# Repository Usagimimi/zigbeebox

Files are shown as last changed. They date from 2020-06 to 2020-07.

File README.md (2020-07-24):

# zigbeebox
Powerful zigbee coordinator with USB and debug port in metal enclosure.

### This project is still under development!!! 

## Description
[Zigbee in general.](https://en.wikipedia.org/wiki/Zigbee)

The coordinator is the central unit of the zigbee network, handling significant RF traffic in most cases. This project offers low-cost open-source hardware for this task, as a remix of many DIY coordinators out there. Takes a bit of time and basic soldering skills to assemble, but it can replace any manufacturers proprietary device when ready. Using the right firmware and server application, you can build a reliable, secure zigbee network without factory restrictions, involving almost any zigbee appliance. This opens the possibility to use IKEA Tradfri lights along with Xiaomi sensors, Philips Hue products, and many more in the same network, without the vendors gateway. The pcb utilizes a cheap chinese CC2538+CC2592 RF module with ARM Cortex-M3 based SoC and enough memory to serve a lot of connections with good performance.

The design heavily relies on open-source code, such as [Zigbee2MQTT](https://www.zigbee2mqtt.io) and various firmware.

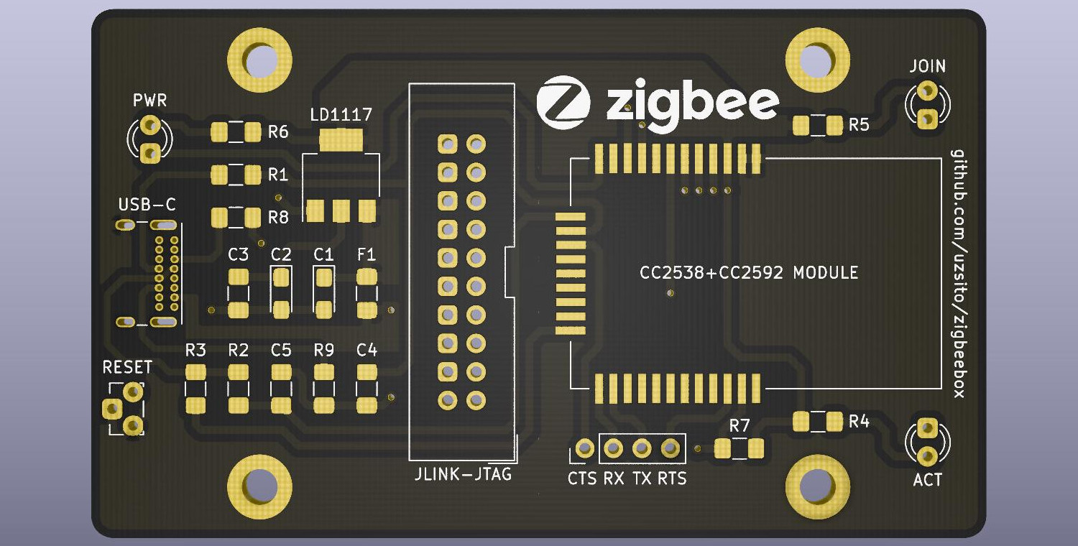
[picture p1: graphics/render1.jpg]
render1

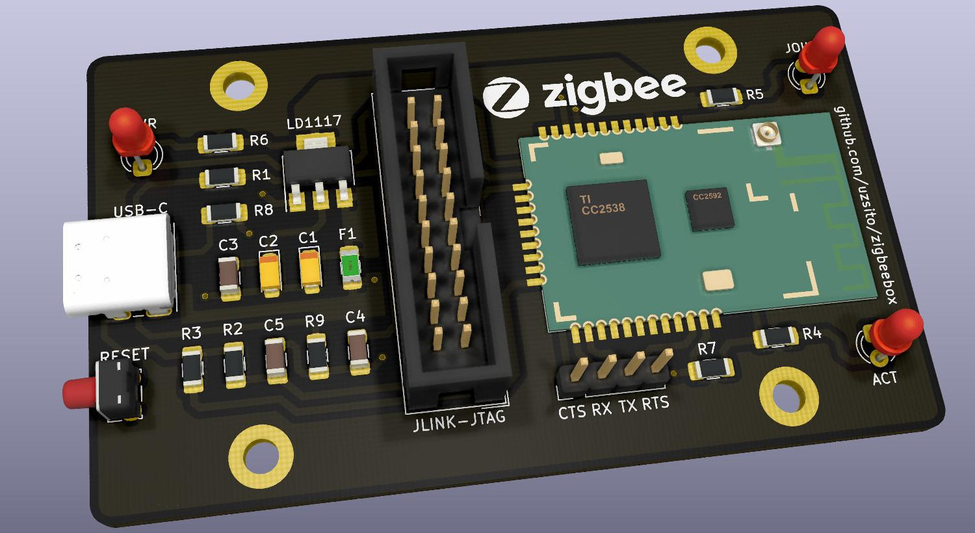
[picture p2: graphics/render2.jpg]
render2

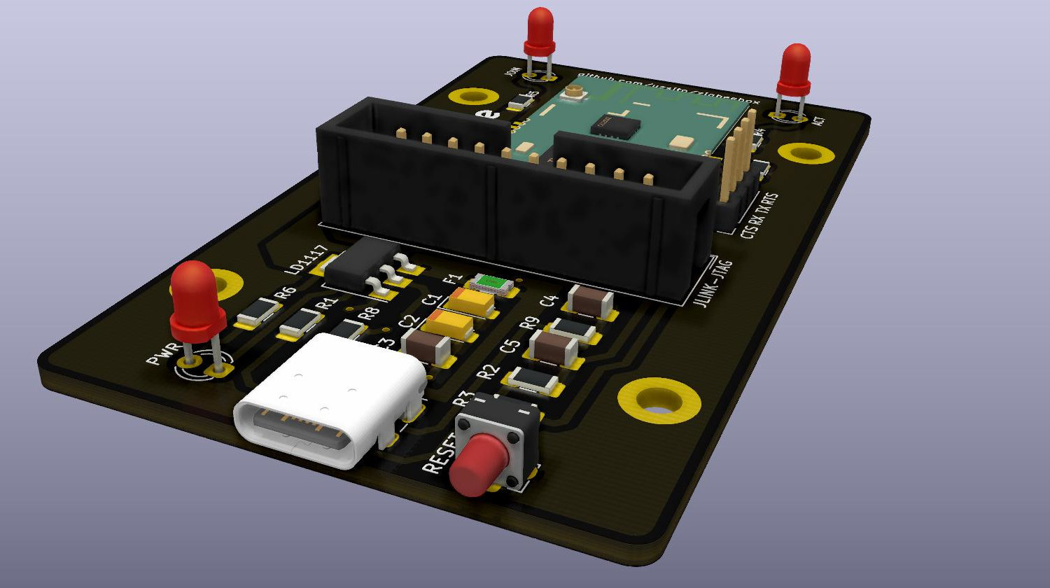
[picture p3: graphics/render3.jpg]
render3

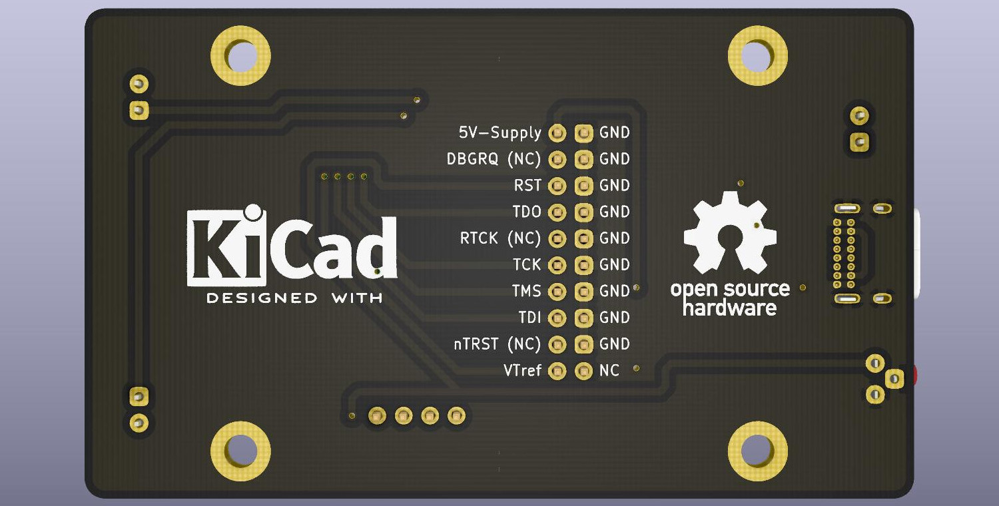
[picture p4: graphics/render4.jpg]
render4


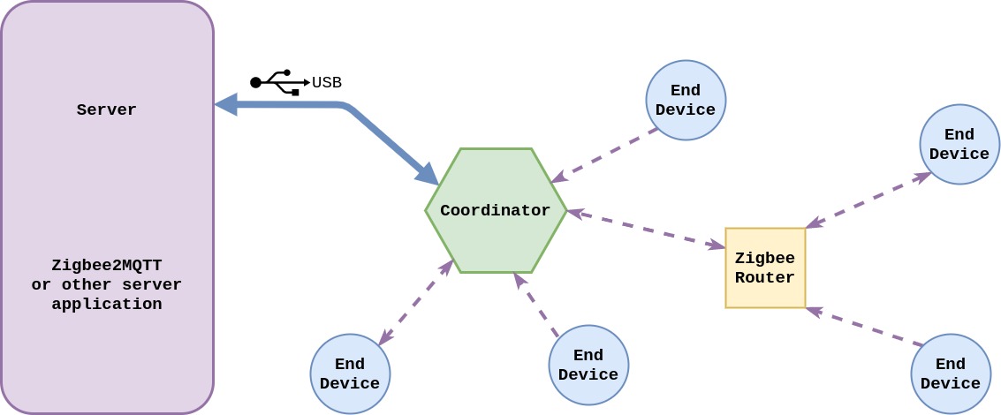
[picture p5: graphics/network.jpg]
network


## Features
* Zigbee 3.0 capable SoC with external antenna connector and RF amplifier frontend
* Use mostly THT and superior SMD components to allow soldering by hand with average tools
* PCB dimensions are designed to fit in a cheap metal enclosure for better shielding
* Avoid dongle-style layout to assist final placement away from any interference
* Mounted with convenient USB Type-C receptacle, detach & orientation sensing
* Plug & play firmware flashing on the J-Link compatible 20pin IDC header
* Indicator LEDs for power, allow join mode, ZNP activity (RF traffic)
* Self-regenerating polyfuse protection for USB host & device

*Since the pcb applies a considerable amount of copper under the CC2538+CC2592 module, it is highly recommended to use the IPEX connector and connect an external antenna, even without metal enclosure.*

## PCB BOM
The following components are needed to assemble the coordinator.

| Component  | Type | Package | Value | Quantity |
| --- | ---- | --- | ----- | --- |
| F1 | Polyfuse | SMD-1206 | Ih=250mA, It=500mA | 1 |
| R1-R2 | Resistor | SMD-1206 | 33Ω | 2 |
| R3 | Resistor | SMD-1206 | 1.5kΩ | 1 |
| R4-R6 | Resistor | SMD-1206 | 100Ω | 3 |
| R7 | Resistor | SMD-1206 | 1kΩ | 1 |
| R8-R9 | Resistor | SMD-1206 | 5.1kΩ | 2 |
| C1-C2 | Tantalum capacitor | SMD-1206 | 10uF | 2 |
| C3 | Capacitor | SMD-1206 | 100nF | 1 |
| C4-C5 | Capacitor | SMD-1206 | 47pF | 2 |
| PWR-JOIN-ACT | LED | 3mm THT | Vf=2.2V, If=10mA | 3 |
| LD1117 | Voltage regulator | SOT223 | LD1117S33TR | 1 |
| USB-C | Receptacle | 16-pin THT | GCT USB4085 | 1 |
| RESET | Tactile switch | 3-pin THT 4.5x4.5mm | TS-C017 | 1 |
| JLINK-JTAG | Connector | 2.54mm IDC double row | 20-pin keyed male | 1 |
| Pin header | Connector | 2.54mm single row | 4-pin male | 1 |

Additional parts:

| Component  | Type | Package | Quantity | Source |
| --- | ---- | --- | --- | --- |
| *[CC2538+CC2592 Module](https://github.com/uzsito/CC2538-CC2592-kicad-component)* | *Zigbee RF board* | *33-pin 20.5x33mmm* | *1* | Aliexpress, Ebay |

## Flashing
You can download and burn compiled firmware from the following repositories:

| Repository  | Firmware | Tested |
| --- | --- | --- |
| [reverieline/CC2538-CC2592-ZNP](https://github.com/reverieline/CC2538-CC2592-ZNP) | MODKAMRU_V3_USB.hex | Tested |
| [antst/CC2538-ZNP-Coordinator-firmware](https://github.com/antst/CC2538-ZNP-Coordinator-firmware) | | Not tested |
| [Koenkk/Z-Stack-firmware](https://github.com/Koenkk/Z-Stack-firmware) | | Not tested |

Flashing methods:
* Using [J-link and J-Flash application](https://github.com/uzsito/zigbeebox/wiki/Flashing-with-JLink), connecting to 20-pin header with ribbon cable (Tested)
* Using [Raspberry Pi and OpenOCD](https://gist.github.com/hwhw/fc43892785aa84913d03495c97b0f25a) connecting with dupont wires (Not tested)

## Enclosure
It is optional to [put the board in a cheap metal case](https://github.com/uzsito/zigbeebox/wiki/Installing-in-metal-box) to achieve better shielding and appearance. The finished pcb fits perfectly in a common box by design, with an applied pigtail to connect your external antenna.

*Finished photos and cutout templates coming soon.*

Former prototype:

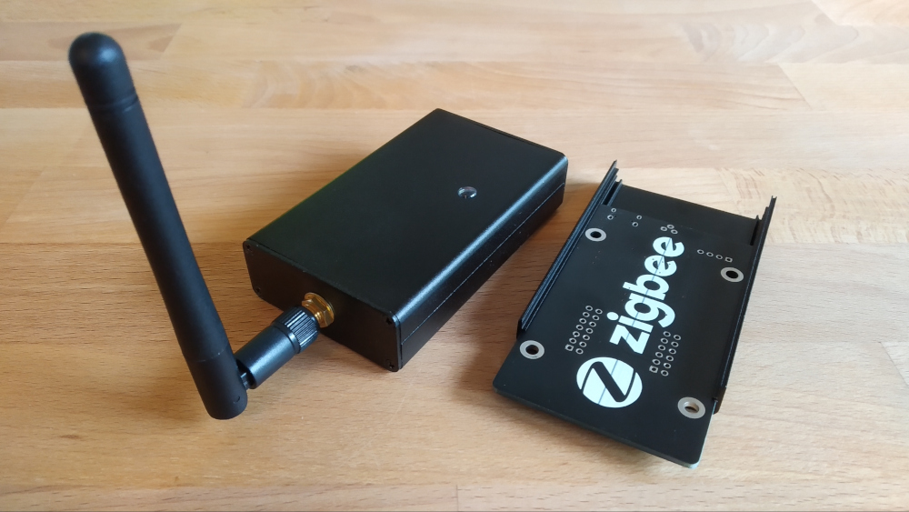
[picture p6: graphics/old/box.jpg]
old

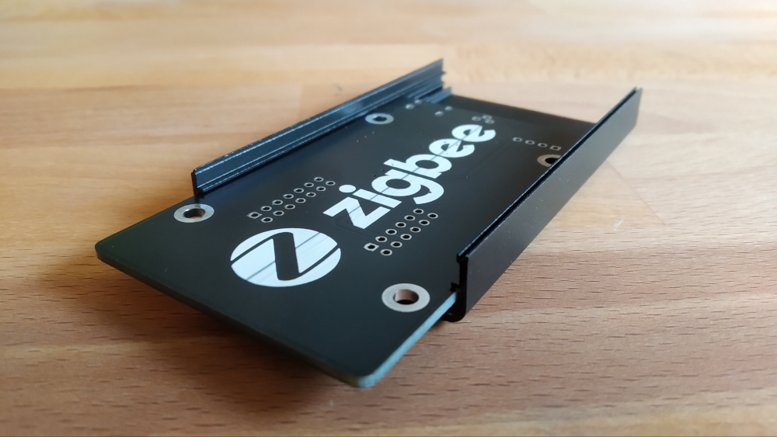
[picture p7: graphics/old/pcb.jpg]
pcb


## Assembly and application
1. Clone or download this repository.
2. Use the prebuilt [gerber archive](kicad_board/gerber/zigbeebox.zip) to print the pcb. Any chinese manufacturer (JLPCB, ALLPCB, PCBWAY, etc.) can fabricate a copy for a couple dollars. Really, it's dirt cheap.
3. Once you got the pcb and the listed components, assemble the coordinator by hand soldering, no special tool needed.
4. Flash the desired firmware with one of the available methods.
5. Connect the board to a machine running zigbee2mqtt or other zigbee server application, and check the log for your new coordinator.

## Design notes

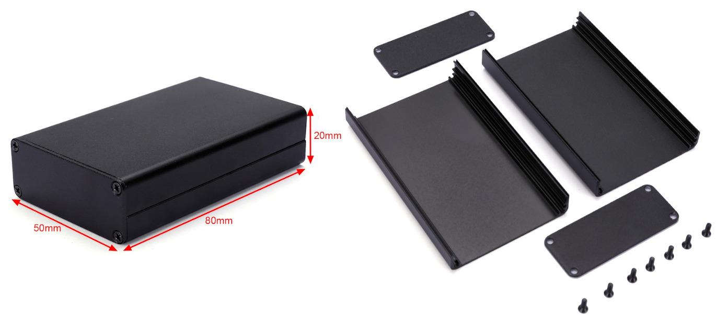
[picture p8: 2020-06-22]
graphics/enclosure.jpg

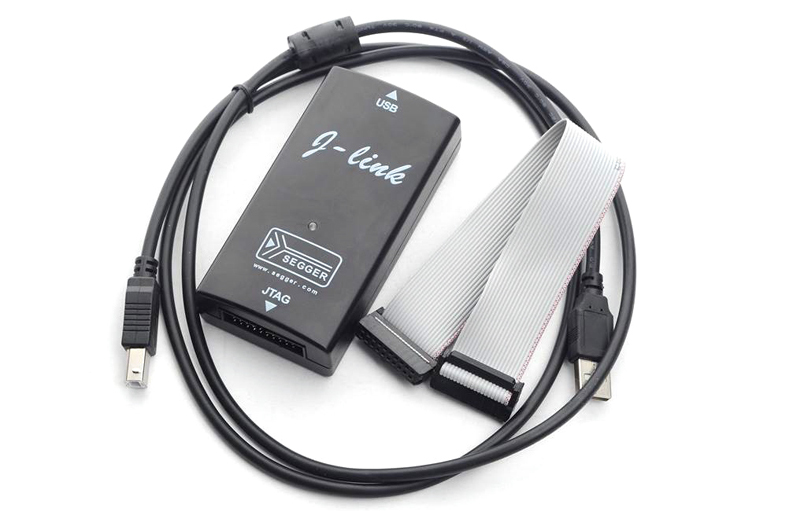
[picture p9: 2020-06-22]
graphics/jlink.jpg

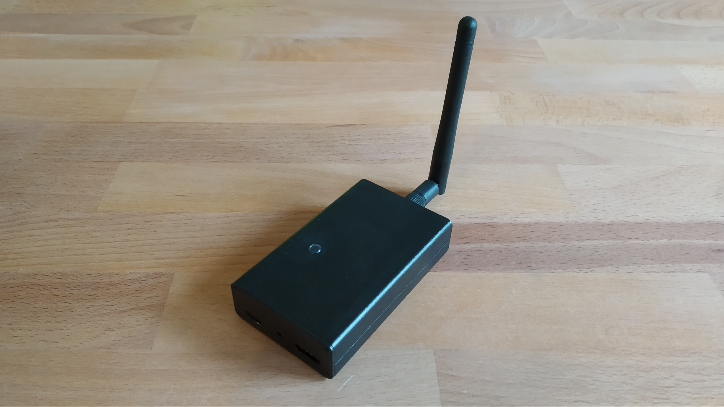
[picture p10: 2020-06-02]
graphics/box1.jpg

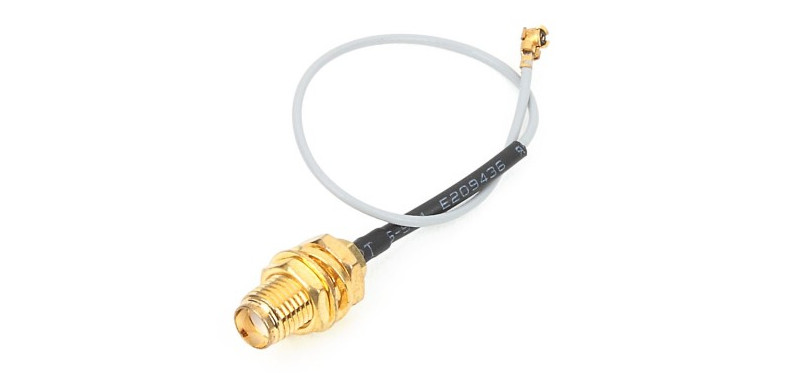
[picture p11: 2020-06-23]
graphics/pigtail.jpg

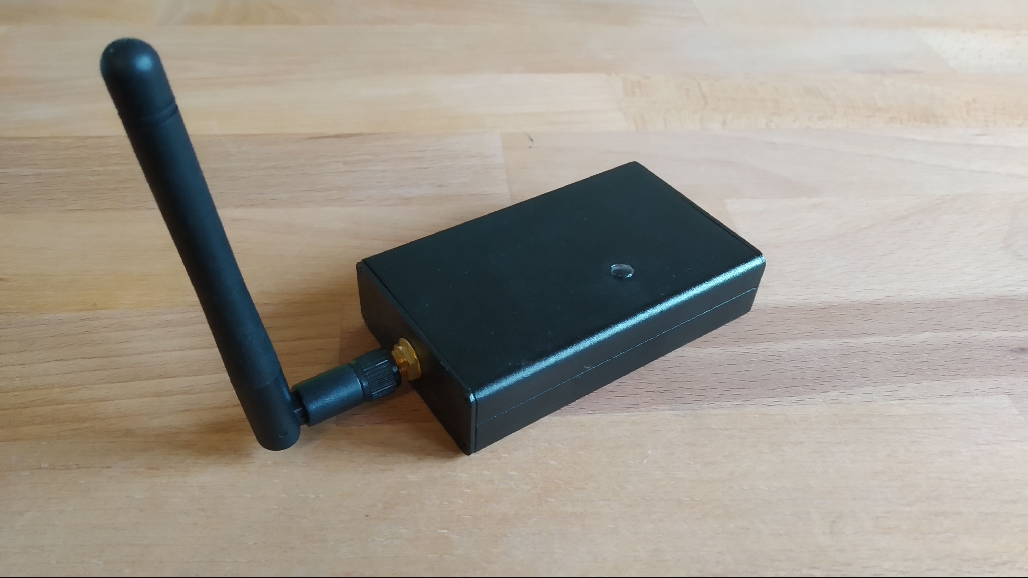
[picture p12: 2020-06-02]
graphics/box3.jpg

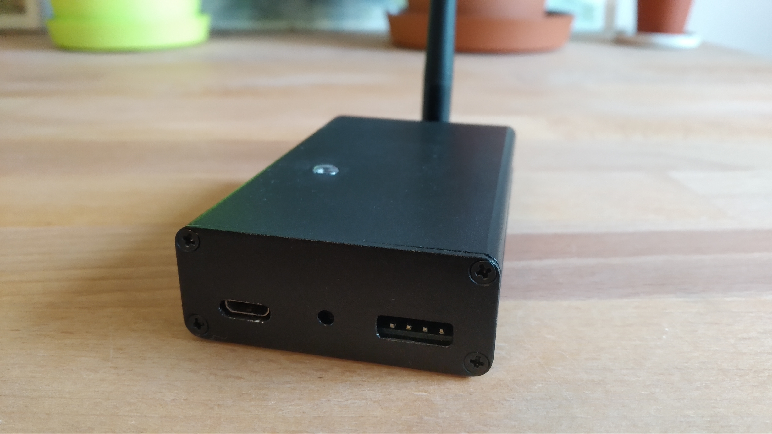
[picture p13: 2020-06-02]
graphics/box2.jpg

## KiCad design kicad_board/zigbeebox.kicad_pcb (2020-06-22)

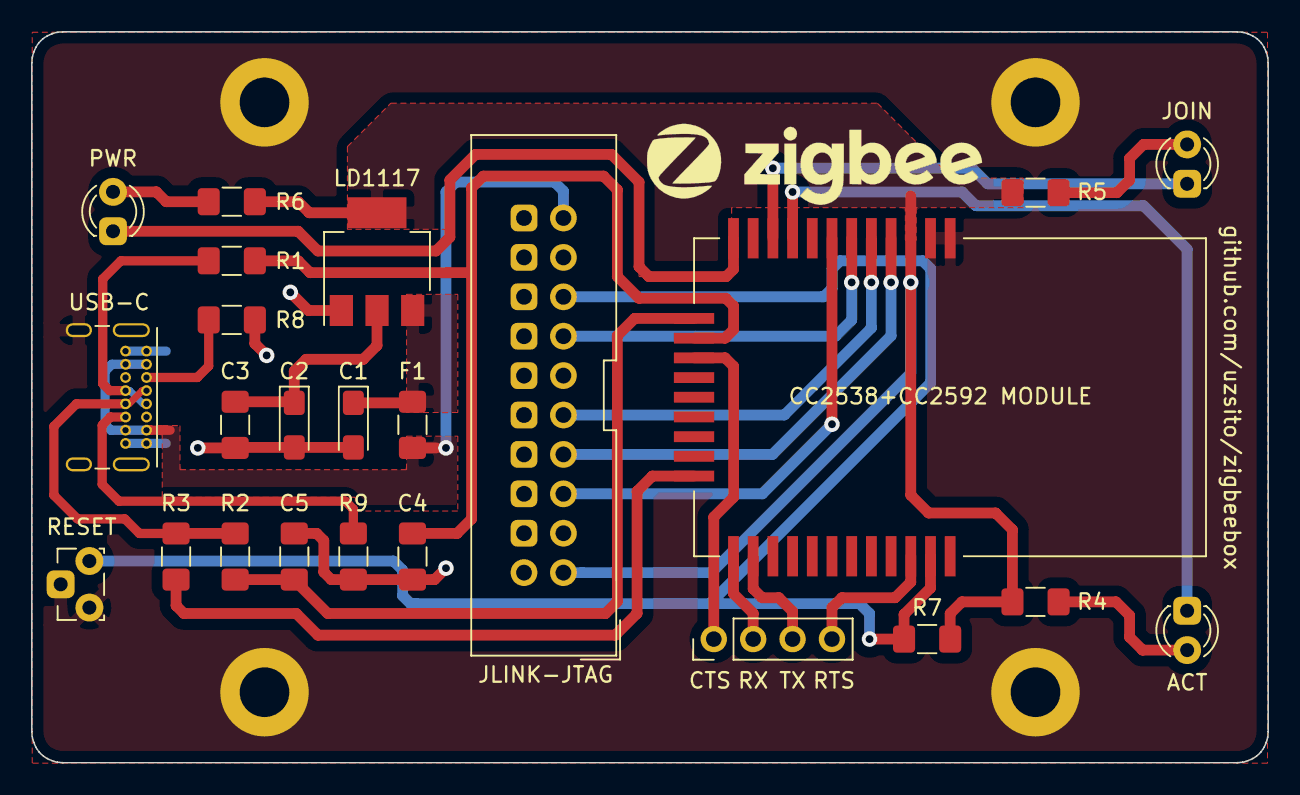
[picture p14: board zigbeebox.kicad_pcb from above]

Board: 2 copper layers, 79.7 x 47.1 mm, 28 parts (0 on the bottom side), 26 nets.

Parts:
C1, C2: 10uF; CP_EIA-3216-12_Kemet-S_Pad1.58x1.35mm_HandSolder
C3: 100nF; C_1206_3216Metric_Pad1.42x1.75mm_HandSolder
C4, C5: 47pF; C_1206_3216Metric_Pad1.42x1.75mm_HandSolder
F1: Fuse; Fuse_1206_3216Metric_Pad1.42x1.75mm_HandSolder
H1, H2, H3, H4: MountingHole_Pad; MountingHole_3.2mm_M3_ISO7380_Pad
J1: Debug; PinHeader_1x04_P2.54mm_Vertical
J2: JLINK-JTAG; IDC-Header_2x10_P2.54mm_Vertical
LD1117: LD1117S33TR_SOT223; SOT-223-3_TabPin2
LED1: ACT; LED_D3.0mm
LED2: JOIN; LED_D3.0mm
LED3: PWR; LED_D3.0mm
R1, R2: 33R; R_1206_3216Metric_Pad1.42x1.75mm_HandSolder
R3: 1.5K; R_1206_3216Metric_Pad1.42x1.75mm_HandSolder
R4, R5, R6: 100R; R_1206_3216Metric_Pad1.42x1.75mm_HandSolder
R7: 1k; R_1206_3216Metric_Pad1.42x1.75mm_HandSolder
R8, R9: 5.1k; R_1206_3216Metric_Pad1.42x1.75mm_HandSolder
SW1: RESET; SW_Tactile_PUSH_Angled_4.5mm_H6.0mm_TS_C017
U1: CC2538+CC2592 MODULE; CC2538_CC2592
USB1: USB-C; USB_C_Receptacle_GCT_USB4085

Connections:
GND: C1.2, C2.2, C3.2, C4.2, C5.2, H1.1, H2.1, H3.1, H4.1, J2.4, J2.6, J2.8, J2.10, J2.12, J2.14, J2.16, J2.18, J2.20, LD1117.1, R8.2, R9.2, SW1.1, SW1.3, U1.1, U1.2, USB1.A1, USB1.A12, USB1.B1, USB1.B12, USB1.S1
unnamed: C1.1, F1.1, LD1117.3
unnamed: C2.1, C3.1, J2.1, LD1117.2, R4.1, R5.1, R6.1, R7.1, U1.3
unnamed: C4.1, R1.2, U1.14
unnamed: C5.1, R2.2, U1.13
unnamed: F1.2, J2.19, USB1.A4, USB1.A9, USB1.B4, USB1.B9
unnamed: J1.1, U1.15
unnamed: J1.2, U1.22
unnamed: J1.3, U1.23
unnamed: J1.4, U1.31
unnamed: J2.5, U1.7
unnamed: J2.7, U1.4
unnamed: J2.9, U1.5
unnamed: J2.13, U1.6
unnamed: J2.15, R7.2, SW1.2, U1.32
unnamed: LED1.1, U1.9
unnamed: LED1.2, R4.2
unnamed: LED2.1, U1.10
unnamed: LED2.2, R5.2
unnamed: LED3.1, U1.12
unnamed: LED3.2, R6.2
unnamed: R1.1, USB1.A7, USB1.B7
unnamed: R2.1, R3.1, USB1.A6, USB1.B6
unnamed: R3.2, U1.21
unnamed: R8.1, USB1.A5
unnamed: R9.1, USB1.B5

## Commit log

2020-06-02 Enclosure pictures
2020-06-21 Kicad board CC2538
    [zigbeebox.kicad_pcb, zigbeebox.sch]
2020-06-21 Gerber files
    [zigbeebox-B_Cu.gbr, zigbeebox-B_Mask.gbr, zigbeebox-B_SilkS.gbr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]
2020-06-21 Upload enclosure pictures
2020-06-22 Minor trace width adjustments
    [zigbeebox.kicad_pcb]
2020-06-22 Gerber update
    [zigbeebox-B_Cu.gbr, zigbeebox-B_Mask.gbr, zigbeebox-B_SilkS.gbr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]
